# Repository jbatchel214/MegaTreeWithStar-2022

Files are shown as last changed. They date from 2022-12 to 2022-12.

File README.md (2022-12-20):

# Mega Tree 2022

In 2022 I built a Mega Tree with a 3D printed, 26 point Moravian star. The tree consisted of 27 strands of ws2811 led pixels. The 3D printed star totaled 113 pixels. The entire tree is controlled by an ESP32.

## Folder Structure

**MegaTreeAndStar**  This is the PlatformIO project of the tree code

**MoravianStar-FreeCAD**  This is the FreeCAD files for the 3D Printed Moravian Star

**MoravianStar-OBJs**  This is all the OBJs used with by the slicer

## Tree Assembly
The 27 strands for the tree are run off 9 pins on the ESP32, meaning 3 strands are run in series off of the pin. The strands are wired such that the strands are wired from bottom to top, then top to bottom, then bottom to top. On that first strand per pin, power is injected. There is additional power injection in between strands 2 and 3:

    Tree Top

        |--->|    |     |--->|    |
        |    |    |     |    |    |
        |    |    |     |    |    |
        |    |    |     |    |    |
        |    |    |     |    |    |
        |    |--->|     |    |--->|   Repeat for remaining strands
        ^    ^          ^    ^ 
       Pin1  |        Pin2   |
            Pwr             Pwr

    Tree Bottom

There are 65 lights per strand, for a total of 195 lights running off each pin. 12mm pixel mounting strips were used to space out the lights and keep them oriented.  I used every 3rd hole for 3" spacing.

There are several options for the center tree support.  I used the "ASAP Pole" and a "Portable Hole" for the base of the tree.  I have 3 guy lines to support it in the case of winds with rebar anchors as supports.

## Star Assembly:

The 3D printed star uses:
 - 17 of the Square Point files
 - 8 of the Triangle Point files
 - 1 of the pipe support
 - 4 of the cross supports
 - 12 of the center light supports
 - 1 of the Pipe Cover Point
 - 88 of the clips (I found an issue with the triangle points where they interfere on adjacent sides - I replaced some of the plastic clips with metal automotive trip clips)
 - you'll also need a 1" steel pipe.  I used an 18" pipe with a matching floor flange on the bottom.
 - you may not need it, but I included grooves for hose clamps (I used 1 to 3" clamps)

1) 4 pixels were installed into each of the square points (including the pipe cover point)
2) 3 pixels were installed into each of the triangle points
3) a single pixel was installed into each of the center lights supports, each of the cross supports, and the main pipe support
4) The center light supports are installed into the square hole in the center of the square points (they just snap in place) - output wires from the center light are fed into the input of the other 4 lights on the square point
5) The four cross supports are also isntalled into the square hole in the center of the square points
Note:  There should be one square point that does not have anything in it's center square hole... the main pipe support will go here, but I found that it was easier to assemble by putting this in last
6) Start with the square point that is missing the center light and attach 2 of the clips to one of its lower edges
7) Take another square point and slide it into the clips, then push the clips in place until they "snap" in.  Connect the wires from the previous point to the next one
8) A triangle point then installs next to that new square, then another square point, etc. all around
9) The next layer is all square points, however 4 of them are the ones with the cross support lights installed (be aware of the orientation of the square hole in the top-most point and the cross supports and how those all align with the main pipe support)
10) The next layer is square points and triangles again
11) Install the main pipe support (You're pushing this into the ball so that the light on the top of it slides into the square hole in the top-most point, and the cross supports settle into the supports in the main pipe support.  I found hanging a string from each of the cross supports helped, then when I went to "snap them in" I pulled down on the string and they popped in place nicely)
12) Slide the pipe cover point down onto the point (you could do this later if you're not using a floor flange)... also, if you have already installed the floor flange then slide the hose clamps into the right place now
13) Slide the main pipe support over the steel pipe, and optionally install the hose clamp over the groove on the main pipe support and tighten
14) Slide the pipe cover point into place, install the hose clamp and tighten (note there's a groove in one corner of the pipe cover point - this is to allow a space for the wires to come out)

I'm not defining connectors or how to make connections.  I leave this to the user based on their project demands.  I also do not describe how I managed power or wired my control box.  I don't think the low voltage of the LED strips pose a risk, but I'm no expert.  And the 120V (or 240V depending on country) can be dangerous, so do your research. 

Known issues with the 3D printed star:
1) Some of the clips interfere especially on adjacent sides of the triangular points, I found these worked well:  https://www.amazon.com/dp/B09PRF2Y5S?psc=1&ref=ppx_yo2ov_dt_b_product_details although you have to spread them a bit or they bite into the plastic
2) The assembly is difficult - a better approach would be a central frame that holds the lights and wiring and points are then "snapped in" from the outside-in
3) The mapping of the LEDs in the 3D star still needs some work

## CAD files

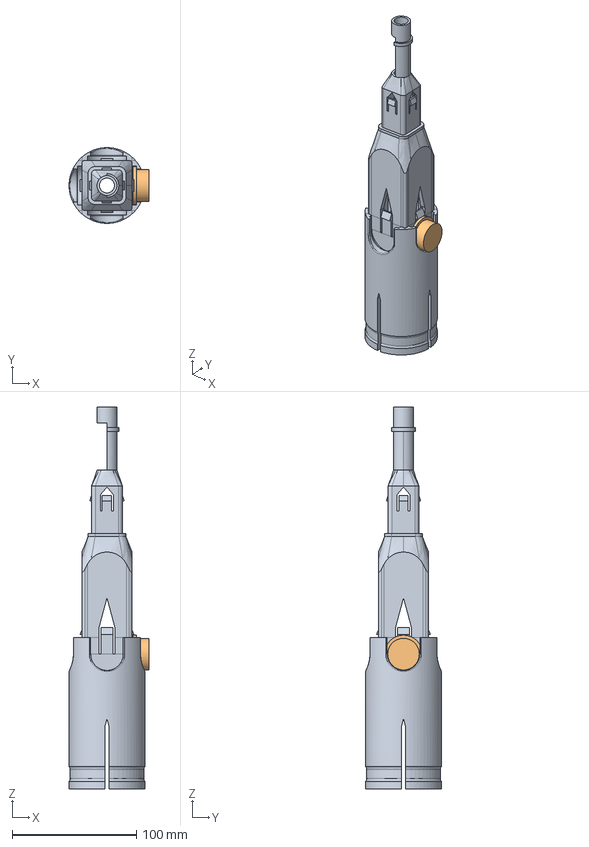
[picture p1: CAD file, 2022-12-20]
MoravianStar-FreeCAD/PipeFitting_R3.FCStd
64.2 x 61.0 x 307.3 mm
PipeSupport

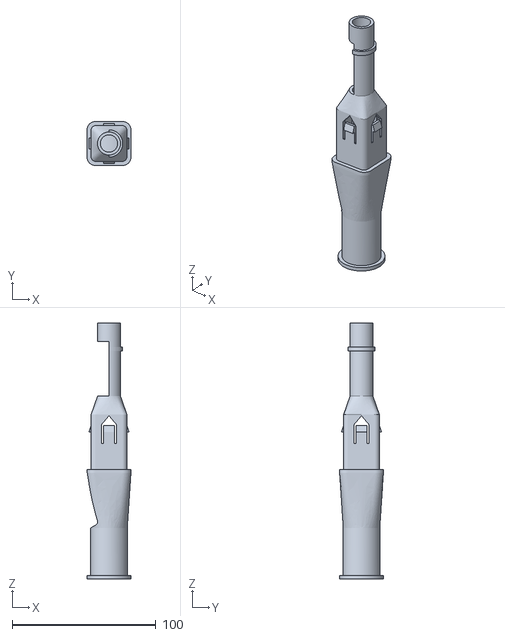
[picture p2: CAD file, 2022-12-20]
MoravianStar-OBJs/CrossSupport_R3-PipeSupport.obj
30.5 x 30.5 x 177.8

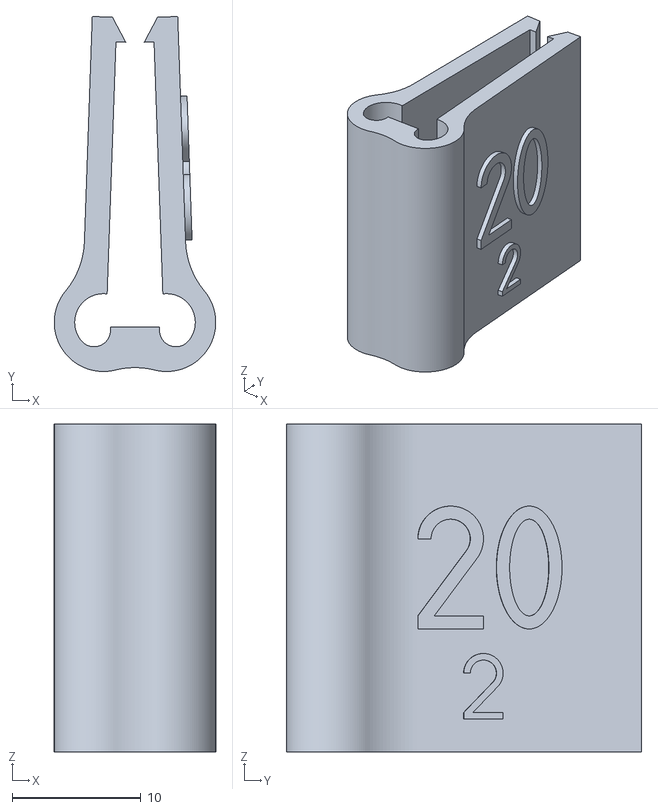
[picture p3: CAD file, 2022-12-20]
MoravianStar-OBJs/Clips_plus020_rev2-Body.obj
12.5 x 27.5 x 25.4

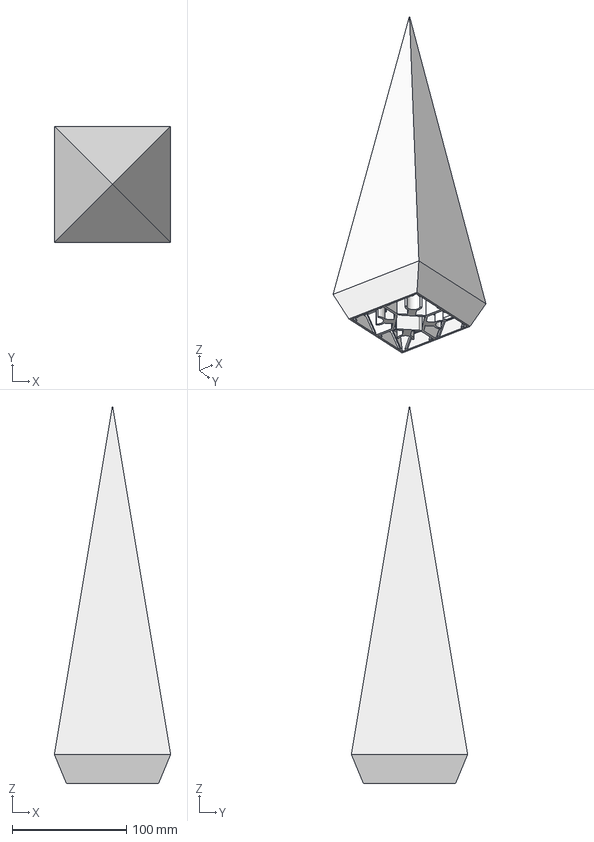
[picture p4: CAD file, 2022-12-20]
MoravianStar-FreeCAD/SquarePoint_4inBase_12inTall_NoBaseReq_rev2.FCStd
101.6 x 101.6 x 330.2 mm

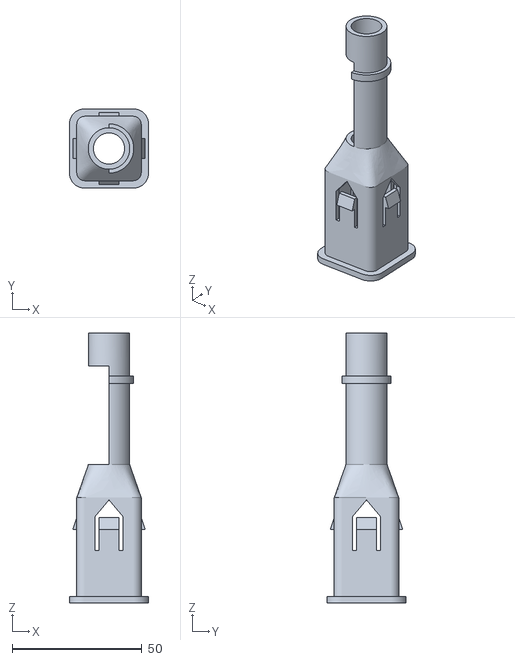
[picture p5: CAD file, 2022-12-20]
MoravianStar-OBJs/CenterLightSupport-Body.obj
30.5 x 30.5 x 104.1

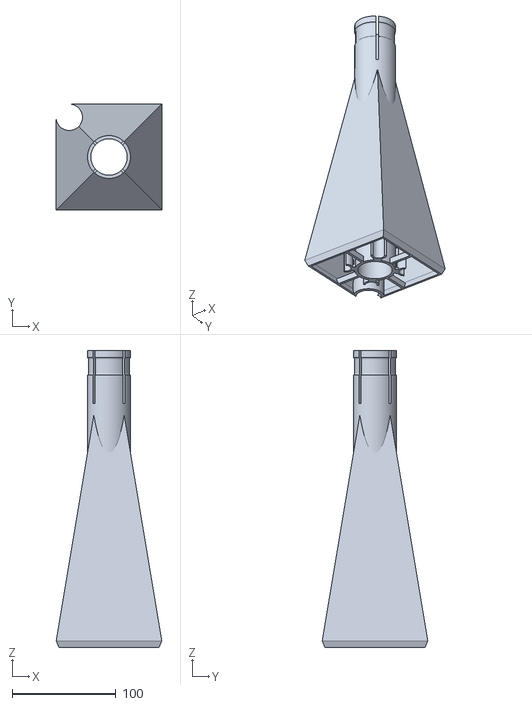
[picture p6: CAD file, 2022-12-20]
MoravianStar-OBJs/Pipe_Cover_Point_rev2-Body.obj
101.6 x 101.6 x 285.7

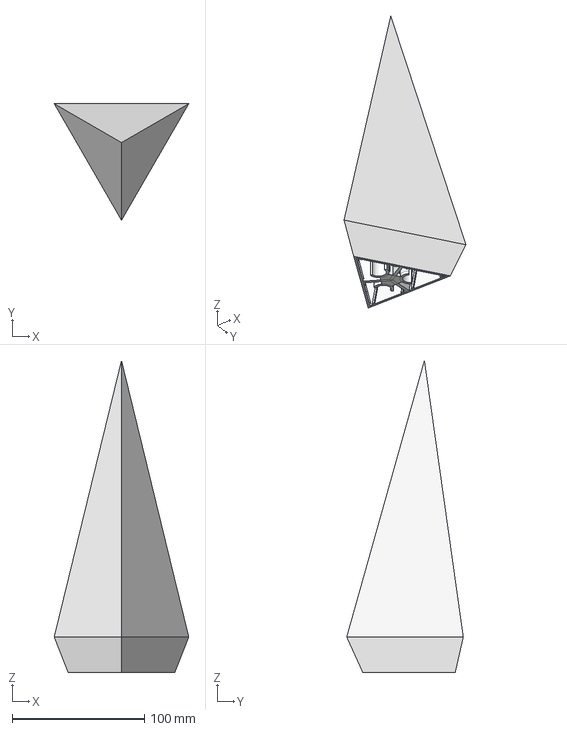
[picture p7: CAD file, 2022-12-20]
MoravianStar-FreeCAD/TrianglePoint_4inBase_7degTaper_NoBaseReq_rev3.FCStd
101.6 x 88.0 x 235.5 mm

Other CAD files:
MoravianStar-FreeCAD/CrossSupport_R3.FCStd
MoravianStar-FreeCAD/Clips_plus020_rev2.FCStd
MoravianStar-OBJs/SquarePoint_4inBase_12inTall_NoBaseReq_rev2-Body.obj
MoravianStar-FreeCAD/CenterLightSupport.FCStd
MoravianStar-OBJs/TrianglePoint_4inBase_7degTaper_NoBaseReq_rev3-Body.obj

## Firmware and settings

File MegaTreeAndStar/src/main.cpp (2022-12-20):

#include <Arduino.h>
#include <FastLED.h>
#include "driver/adc.h"

void clamp(int &val, int min, int max);
CRGB blendRGB(CRGB & startRGB, CRGB & endRGB, float pcnt);
bool angleInRange(float val, float minT, float maxT);
void SetupStar();
void SetupXMASTree();
void SetStarHSV(CHSV hsvLoc);
void SetTreeHSV(CHSV hsvLoc);
void TreeColorDrops(CHSV hsvBase);
//void TreeSpiralSolid(CHSV hsvBase, float theta, float dTheta, float omega, CHSV spiral);
void TreeSpiralRainbow(CHSV hsvBase, float theta, float dTheta, float omega, uint8_t spiralType, CHSV spiralStart, float spiraldTheta);
void TreeMeteors(CHSV hsvBase);
void CyclePixelColors(uint8_t deltaVal);
void CyclePointColors(uint8_t shiftVal, uint8_t deltaVal);

#define BRIGHTNESS 255
#define starValue 255
#define treeValue 155

#define STARPIN 27
#define NUMSTARLEDS 113

#define STRANDPIN00 16
#define STRANDPIN01 17
#define STRANDPIN02 18
#define STRANDPIN03 19
#define STRANDPIN04 21
#define STRANDPIN05 22
#define STRANDPIN06 23
#define STRANDPIN07 25
#define STRANDPIN08 26
#define NUMSTRANDLEDS 65
#define NUMSTRANDS 27
#define NUMSTRANDSPERPIN 3
#define NUMSTRANDPINS NUMSTRANDS/NUMSTRANDSPERPIN
#define NUMSTRANDLEDSPERPIN NUMSTRANDSPERPIN * NUMSTRANDLEDS
#define NUMTREELEDS NUMSTRANDS*NUMSTRANDLEDS

/* LED Arrays */
CRGB starLEDs[NUMSTARLEDS];
CRGB strandLEDsWired[NUMSTRANDPINS][NUMSTRANDLEDSPERPIN]; // these are as-wired, so bottom to top, top to bottom, bottom to top

/* universal constants */
float pi = 2.0*acosf(0.0);
float d2r = pi/180;
float r2d = 180/pi;


/* define geometries */

// define tree geometry
float firstAngle_rad = -130.0*d2r;
float lastAngle_rad = 130.0*d2r;
float baseDiam_in = 120.0;
float topDiam_in = 12.0;
float spaceInit_in = 3.0;
float spaceFinal_in = 3.0;
float gapPerLights_in = 3.0;
float vertexHeight_in = 0.0;
float treeX[NUMSTRANDPINS][NUMSTRANDLEDSPERPIN]; // x is towards road
float treeY[NUMSTRANDPINS][NUMSTRANDLEDSPERPIN]; // y is towards driveway
float treeZ[NUMSTRANDPINS][NUMSTRANDLEDSPERPIN]; // z is vertical up
float treeR[NUMSTRANDPINS][NUMSTRANDLEDSPERPIN]; // radially from center
float treeL[NUMSTRANDPINS][NUMSTRANDLEDSPERPIN]; // Length along strand
float treeT[NUMSTRANDPINS][NUMSTRANDLEDSPERPIN]; // Theta, measured from +X towards +Y (about +Z)
int treeLEDMap[NUMSTRANDS][NUMSTRANDLEDS][2]; // index map of each strand, sorted bottom to top per strand - useful for following something down a strand



// define star geoemtry
int starPoint[NUMSTARLEDS] = {0, 0, 0, 0, 0, 8, 8, 8, 8, 8, 7, 7, 7, 6, 6, 6, 6, 6, 5, 5, 5, 4, 4, 4, 4, 4, 3, 3, 3, 2, 2, 2, 2, 2, 1, 1, 1, 16, 16, 16, 16, 16, 15, 15, 15, 15, 15, 14, 14, 14, 14, 14, 13, 13, 13, 13, 13, 12, 12, 12, 12, 12, 11, 11, 11, 11, 11, 10, 10, 10, 10, 10, 9, 9, 9, 9, 9, 17, 17, 17, 24, 24, 24, 24, 24, 23, 23, 23, 22, 22, 22, 22, 22, 21, 21, 21, 20, 20, 20, 20, 20, 19, 19, 19, 18, 18, 18, 18, 18, 25, 25, 25, 25};
int starPointType[NUMSTARLEDS] = {0, 0, 0, 0, 0, 0, 0, 0, 0, 0, 1, 1, 1, 0, 0, 0, 0, 0, 1, 1, 1, 0, 0, 0, 0, 0, 1, 1, 1, 0, 0, 0, 0, 0, 1, 1, 1, 0, 0, 0, 0, 0, 0, 0, 0, 0, 0, 0, 0, 0, 0, 0, 0, 0, 0, 0, 0, 0, 0, 0, 0, 0, 0, 0, 0, 0, 0, 0, 0, 0, 0, 0, 0, 0, 0, 0, 0, 1, 1, 1, 0, 0, 0, 0, 0, 1, 1, 1, 0, 0, 0, 0, 0, 1, 1, 1, 0, 0, 0, 0, 0, 1, 1, 1, 0, 0, 0, 0, 0, 0, 0, 0, 0};
int starLocation[NUMSTARLEDS] = {0, 4, 1, 2, 3, 0, 2, 1, 4, 3, 10, 2, 1, 0, 1, 2, 3, 4, 0, 2, 1, 0, 4, 3, 2, 1, 2, 1, 0, 0, 4, 3, 2, 1, 2, 1, 0, 0, 4, 3, 2, 1, 0, 2, 1, 4, 3, 0, 1, 2, 3, 4, 0, 3, 2, 1, 4, 0, 1, 4, 3, 2, 0, 3, 2, 1, 4, 0, 4, 3, 2, 1, 0, 2, 3, 4, 1, 2, 1, 0, 0, 2, 3, 4, 1, 0, 2, 1, 0, 4, 3, 2, 1, 0, 2, 1, 0, 2, 3, 4, 1, 2, 0, 1, 0, 4, 3, 2, 1, 4, 3, 2, 1};
float starRadius[NUMSTARLEDS] = {8.000, 5.000, 5.000, 5.000, 5.000, 8.000, 5.000, 5.000, 5.000, 5.000, 5.000, 5.000, 5.000, 8.000, 5.000, 5.000, 5.000, 5.000, 5.000, 5.000, 5.000, 8.000, 5.000, 5.000, 5.000, 5.000, 5.000, 5.000, 5.000, 8.000, 5.000, 5.000, 5.000, 5.000, 5.000, 5.000, 5.000, 8.000, 5.000, 5.000, 5.000, 5.000, 8.000, 5.000, 5.000, 5.000, 5.000, 8.000, 5.000, 5.000, 5.000, 5.000, 8.000, 5.000, 5.000, 5.000, 5.000, 8.000, 5.000, 5.000, 5.000, 5.000, 8.000, 5.000, 5.000, 5.000, 5.000, 8.000, 5.000, 5.000, 5.000, 5.000, 8.000, 5.000, 5.000, 5.000, 5.000, 5.000, 5.000, 5.000, 8.000, 5.000, 5.000, 5.000, 5.000, 5.000, 5.000, 5.000, 8.000, 5.000, 5.000, 5.000, 5.000, 5.000, 5.000, 5.000, 8.000, 5.000, 5.000, 5.000, 5.000, 5.000, 5.000, 5.000, 8.000, 5.000, 5.000, 5.000, 5.000, 5.000, 5.000, 5.000, 5.000};
float starAzimuth[NUMSTARLEDS] = {0.000, 270.000, 0.000, 90.000, 180.000, 315.000, 326.250, 303.750, 300.000, 330.000, 270.000, 281.250, 258.750, 225.000, 213.750, 236.250, 240.000, 210.000, 180.000, 191.250, 168.750, 135.000, 120.000, 150.000, 146.250, 123.750, 101.250, 78.750, 90.000, 45.000, 30.000, 60.000, 56.250, 33.750, 11.250, 348.750, 0.000, 315.000, 303.750, 326.250, 326.250, 303.750, 270.000, 281.250, 258.750, 258.750, 281.250, 225.000, 213.750, 236.250, 236.250, 213.750, 180.000, 191.250, 191.250, 168.750, 168.750, 135.000, 123.750, 123.750, 146.250, 146.250, 90.000, 101.250, 101.250, 78.750, 78.750, 45.000, 33.750, 56.250, 56.250, 33.750, 0.000, 11.250, 11.250, 348.750, 348.750, 11.250, 0.000, 348.750, 315.000, 330.000, 326.250, 303.750, 300.000, 258.750, 281.250, 270.000, 225.000, 213.750, 236.250, 240.000, 210.000, 168.750, 191.250, 180.000, 135.000, 150.000, 146.250, 123.750, 120.000, 101.250, 78.750, 90.000, 45.000, 33.750, 56.250, 60.000, 30.000, 180.000, 270.000, 0.000, 90.000};
float starElevation[NUMSTARLEDS] = {0.000, 15.000, 15.000, 15.000, 15.000, 45.000, 60.000, 60.000, 30.000, 30.000, 30.000, 60.000, 60.000, 45.000, 60.000, 60.000, 30.000, 30.000, 30.000, 60.000, 60.000, 45.000, 30.000, 30.000, 60.000, 60.000, 60.000, 60.000, 30.000, 45.000, 30.000, 30.000, 60.000, 60.000, 60.000, 60.000, 30.000, 90.000, 75.000, 75.000, 105.000, 105.000, 90.000, 105.000, 105.000, 75.000, 75.000, 90.000, 105.000, 105.000, 75.000, 75.000, 90.000, 75.000, 105.000, 105.000, 75.000, 90.000, 105.000, 75.000, 75.000, 105.000, 90.000, 75.000, 105.000, 105.000, 75.000, 90.000, 75.000, 75.000, 105.000, 105.000, 90.000, 105.000, 75.000, 75.000, 105.000, 120.000, 150.000, 120.000, 135.000, 150.000, 120.000, 120.000, 150.000, 120.000, 120.000, 150.000, 135.000, 120.000, 120.000, 150.000, 150.000, 120.000, 120.000, 150.000, 135.000, 150.000, 120.000, 120.000, 150.000, 120.000, 120.000, 150.000, 135.000, 120.000, 120.000, 150.000, 150.000, 165.000, 165.000, 165.000, 165.000};
float starX[NUMSTARLEDS] = {0.000, 0.000, 1.294, 0.000, -1.294, 4.000, 3.600, 2.406, 1.250, 2.165, 0.000, 0.845, -0.845, -4.000, -3.600, -2.406, -1.250, -2.165, -2.500, -4.247, -4.247, -4.000, -1.250, -2.165, -3.600, -2.406, -0.845, 0.845, 0.000, 4.000, 2.165, 1.250, 2.406, 3.600, 4.247, 4.247, 2.500, 5.657, 2.683, 4.016, 4.016, 2.683, 0.000, 0.942, -0.942, -0.942, 0.942, -5.657, -4.016, -2.683, -2.683, -4.016, -8.000, -4.737, -4.737, -4.737, -4.737, -5.657, -2.683, -2.683, -4.016, -4.016, 0.000, -0.942, -0.942, 0.942, 0.942, 5.657, 4.016, 2.683, 2.683, 4.016, 8.000, 4.737, 4.737, 4.737, 4.737, 4.247, 2.500, 4.247, 4.000, 2.165, 3.600, 2.406, 1.250, -0.845, 0.845, 0.000, -4.000, -3.600, -2.406, -1.250, -2.165, -4.247, -4.247, -2.500, -4.000, -2.165, -3.600, -2.406, -1.250, -0.845, 0.845, 0.000, 4.000, 3.600, 2.406, 1.250, 2.165, -1.294, 0.000, 1.294, 0.000};
float starY[NUMSTARLEDS] = {0.000, -1.294, 0.000, 1.294, 0.000, -4.000, -2.406, -3.600, -2.165, -1.250, -2.500, -4.247, -4.247, -4.000, -2.406, -3.600, -2.165, -1.250, 0.000, -0.845, 0.845, 4.000, 2.165, 1.250, 2.406, 3.600, 4.247, 4.247, 2.500, 4.000, 1.250, 2.165, 3.600, 2.406, 0.845, -0.845, 0.000, -5.657, -4.016, -2.683, -2.683, -4.016, -8.000, -4.737, -4.737, -4.737, -4.737, -5.657, -2.683, -4.016, -4.016, -2.683, 0.000, -0.942, -0.942, 0.942, 0.942, 5.657, 4.016, 4.016, 2.683, 2.683, 8.000, 4.737, 4.737, 4.737, 4.737, 5.657, 2.683, 4.016, 4.016, 2.683, 0.000, 0.942, 0.942, -0.942, -0.942, 0.845, 0.000, -0.845, -4.000, -1.250, -2.406, -3.600, -2.165, -4.247, -4.247, -2.500, -4.000, -2.406, -3.600, -2.165, -1.250, 0.845, -0.845, 0.000, 4.000, 1.250, 2.406, 3.600, 2.165, 4.247, 4.247, 2.500, 4.000, 2.406, 3.600, 2.165, 1.250, 0.000, -1.294, 0.000, 1.294};
float starZ[NUMSTARLEDS] = {8.000, 4.830, 4.830, 4.830, 4.830, 5.657, 2.500, 2.500, 4.330, 4.330, 4.330, 2.500, 2.500, 5.657, 2.500, 2.500, 4.330, 4.330, 4.330, 2.500, 2.500, 5.657, 4.330, 4.330, 2.500, 2.500, 2.500, 2.500, 4.330, 5.657, 4.330, 4.330, 2.500, 2.500, 2.500, 2.500, 4.330, 0.000, 1.294, 1.294, -1.294, -1.294, 0.000, -1.294, -1.294, 1.294, 1.294, 0.000, -1.294, -1.294, 1.294, 1.294, 0.000, 1.294, -1.294, -1.294, 1.294, 0.000, -1.294, 1.294, 1.294, -1.294, 0.000, 1.294, -1.294, -1.294, 1.294, 0.000, 1.294, 1.294, -1.294, -1.294, 0.000, -1.294, 1.294, 1.294, -1.294, -2.500, -4.330, -2.500, -5.657, -4.330, -2.500, -2.500, -4.330, -2.500, -2.500, -4.330, -5.657, -2.500, -2.500, -4.330, -4.330, -2.500, -2.500, -4.330, -5.657, -4.330, -2.500, -2.500, -4.330, -2.500, -2.500, -4.330, -5.657, -2.500, -2.500, -4.330, -4.330, -4.830, -4.830, -4.830, -4.830};



int starPattern = 1;
int treePattern = 3;
bool treeTransition = false;

void setup() {
  // put your setup code here, to run once:
  adc_power_acquire(); // this was done because of an interrupt issue causing flickering

  //Serial.begin(115200);

  // setup star geometry
  //Serial.println("Starting Tree Setup");
  // setup tree geometry
  SetupXMASTree();
  //Serial.println("Finished Tree Setup");

  FastLED.addLeds<WS2811, STARPIN, RGB>(starLEDs, NUMSTARLEDS);
  //FastLED.addLeds<WS2811, STRANDPIN01, RGB>(strandLEDsIdeal[0], NUMSTRANDLEDS);
  FastLED.addLeds<WS2811, STRANDPIN00, RGB>(strandLEDsWired[0], NUMSTRANDLEDSPERPIN);
  FastLED.addLeds<WS2811, STRANDPIN01, RGB>(strandLEDsWired[1], NUMSTRANDLEDSPERPIN);
  FastLED.addLeds<WS2811, STRANDPIN02, RGB>(strandLEDsWired[2], NUMSTRANDLEDSPERPIN);
  FastLED.addLeds<WS2811, STRANDPIN03, RGB>(strandLEDsWired[3], NUMSTRANDLEDSPERPIN);
  FastLED.addLeds<WS2811, STRANDPIN04, RGB>(strandLEDsWired[4], NUMSTRANDLEDSPERPIN);
  FastLED.addLeds<WS2811, STRANDPIN05, RGB>(strandLEDsWired[5], NUMSTRANDLEDSPERPIN);
  FastLED.addLeds<WS2811, STRANDPIN06, RGB>(strandLEDsWired[6], NUMSTRANDLEDSPERPIN);
  FastLED.addLeds<WS2811, STRANDPIN07, RGB>(strandLEDsWired[7], NUMSTRANDLEDSPERPIN);
  FastLED.addLeds<WS2811, STRANDPIN08, RGB>(strandLEDsWired[8], NUMSTRANDLEDSPERPIN);
  
  // set the global brightness parameter
  FastLED.setBrightness(BRIGHTNESS);

}

void loop() {
  static unsigned long dTime = 20;
  static unsigned long frms = 0;
  const static unsigned long maxFrms = 1000;
  const static int transitionFrms = 40;
  const static int transitionRate = BRIGHTNESS/(transitionFrms-1);
  //static int transitionFrameCount = -transitionFrms;

  switch (starPattern) {
    case 0: {// solid star, vary hue vs time
      static uint8_t frameCnt = 0;
      static CHSV hsvLoc = {0, 255, starValue};
      SetStarHSV(hsvLoc);
      frameCnt++;
      if(frameCnt > 2) {
        hsvLoc.h++;
        frameCnt = 0;
      }
      break;
    }
    case 1: {// individual points cycle their own colors
      static uint8_t shiftVal = 10; // shift from time step to time step
      static uint8_t deltaVal = 70; // delta from point to point
      CyclePointColors(shiftVal, deltaVal);
      break;
    }
    case 2: { // cycle all pixels uniquely
      static uint8_t deltaVal = 70; // delta from point to point
      CyclePixelColors(deltaVal);
      break;
    }
    default: {
      starPattern = 0;
      break;
    }
  }
  //FastLED.show();
  
  switch (treePattern) {
    case 0: {// solid tree, vary hue vs time
      static CHSV hsvLoc = {0, 255, treeValue};
      SetTreeHSV(hsvLoc);
      hsvLoc.h++;
      break;
    }
    case 1: { // solid tree, but "drops" of color
      static CHSV hsvBase = rgb2hsv_approximate(CRGB::DarkGreen);
      TreeColorDrops(hsvBase);
      break;
    }
    case 2: { // tree spiral
      static CHSV hsvBase = rgb2hsv_approximate(CRGB::DarkGreen);
      static CHSV spiral = rgb2hsv_approximate(CRGB::Purple);
      static float theta_rad = 0.0*d2r;
      static float deltaTheta_rad = 180.0*d2r;
      static float omega_rps = 10.0*d2r;
      //theta_rad = fmodf(theta_rad+pi, 2*pi)-pi;
      TreeSpiralRainbow(hsvBase, theta_rad, deltaTheta_rad, omega_rps, 0, spiral, 0.0);
      theta_rad += 3.0*d2r;
      break;
    }//*/
    case 3: { // rainbow spiral
      static CHSV hsvBase = rgb2hsv_approximate(CRGB::DarkGreen);
      static CHSV spiral = {0,255,treeValue};
      static float theta_rad = 0.0*d2r;
      static float deltaTheta_rad = 180.0*d2r;
      static float omega_rps = 10.0*d2r;
      //theta_rad = fmodf(theta_rad+pi, 2*pi)-pi;
      TreeSpiralRainbow(hsvBase, theta_rad, deltaTheta_rad, omega_rps, 1, spiral, 4.0);
      theta_rad += 3.0*d2r;
      spiral.h+=10;
      break;
    }//*/
    default: {
      treePattern = 0;
      break;
    }
  }

  frms++;
  int tmpBrightness = BRIGHTNESS;
  if (frms<transitionFrms){ // initial ramp up in brightness
    tmpBrightness = transitionRate * frms;
    clamp(tmpBrightness, 0, 255);
  }
  else if (frms<transitionFrms + maxFrms) { // constant brightness
    tmpBrightness = BRIGHTNESS;
  }
  else if (frms<transitionFrms + maxFrms + transitionFrms) { // rampdown to transition
    int transitionCnt = transitionFrms - (frms - transitionFrms - maxFrms);
    tmpBrightness = transitionRate * transitionCnt;
    clamp(tmpBrightness, 0, 255);
    FastLED.setBrightness(tmpBrightness);
  } else {
    tmpBrightness = 0;
    treePattern++;
    frms = 0;
    //Serial.printf(" New Tree Pattern:  %d\n", treePattern);
  }
  //Serial.printf("Frame:  %d     Brightness:  %d\n", frms, tmpBrightness);
  FastLED.setBrightness(tmpBrightness);

  FastLED.show();
  FastLED.delay(dTime);

}


/* Utility Functions */
void clamp(int &val, int min, int max) {
  if (val < min) {
    val = min;
  }
  else if (val > max) {
    val = max;
  }
}

CRGB blendRGB(CRGB & startRGB, CRGB & endRGB, float pcnt) {
  CRGB output;
  // Linearly interpolates in R, G, B color space between 2 colors
  int tmpRed   = int(float(endRGB.r - startRGB.r)*pcnt + float(startRGB.r) + 0.5);
  int tmpGreen = int(float(endRGB.g - startRGB.g)*pcnt + float(startRGB.g) + 0.5);
  int tmpBlue  = int(float(endRGB.b - startRGB.b)*pcnt + float(startRGB.b) + 0.5);
  clamp(tmpRed, 0, 255);
  clamp(tmpGreen, 0, 255);
  clamp(tmpBlue, 0, 255);
  output.r = tmpRed;
  output.g = tmpGreen;
  output.b = tmpBlue;
  return output;
}

bool angleInRange(float val, float minT, float maxT) {
  // checks if an angle is between min and max angle (around a 360deg circle)
  val = fmodf(val + pi, 2*pi) - pi;
  minT = fmodf(minT + pi, 2*pi) - pi;
  maxT = fmodf(maxT + pi, 2*pi) - pi;
  if (maxT > minT) {
    if ((minT <= val) & (val <= maxT)) { return true; }
    else { return false; }
  }
  else {
    if ((maxT <  val) & (val <  minT)) { return false; }
    else { return true; }
  }
}

float smallestAngle(float val, float ref) {
  // finds the smallest angle between the val and the ref, non directional
  float diff = fmodf(val - ref + pi, 2*pi) - pi;
  diff = (diff < -pi) ? diff + 2*pi : diff;
  return (diff < 0) ? -diff : diff;
}

/* Setup Functions */

void SetupStar() {}

void SetupXMASTree() {
  //Serial.println("Detailed Tree Setup");
  // strands are wired in pairs of 3, going bottom to top, top to bottom, bottom to top
  float strandLength_in = float(NUMSTRANDLEDS - 1)*gapPerLights_in + spaceInit_in + spaceFinal_in;
  float verticalLength_in = sqrt(strandLength_in*strandLength_in - (0.5*(baseDiam_in - topDiam_in))*(0.5*(baseDiam_in - topDiam_in)));
  vertexHeight_in = verticalLength_in * baseDiam_in / (baseDiam_in - topDiam_in);
  float vertexLength_in = sqrt(vertexHeight_in*vertexHeight_in + baseDiam_in*baseDiam_in);
  float strandTiltAngle_rad = atan2f(baseDiam_in - topDiam_in, verticalLength_in);
  
  int iStrand = 0;
  for (int iP = 0; iP<NUMSTRANDPINS; iP++) { // pin, there's 9 pins and there's 3 strands per pin
    bool bottomUp = true;
    int iLwired = 0; // index of the light as it's wired on the pin
    for (int iS = 0; iS<NUMSTRANDSPERPIN; iS++) { // strand, there's 3 strands per pin
    float tmpAng = firstAngle_rad + ((lastAngle_rad - firstAngle_rad)/(float(NUMSTRANDS)-1.0))*float(iStrand);
      for (int iLcnt = 0; iLcnt<NUMSTRANDLEDS; iLcnt++) {
        // determines if you count up or down:
        int iL = (bottomUp) ? iLcnt : (NUMSTRANDLEDS-1) - iLcnt;

        // map the LEDs from "ideal" to wired:
        treeLEDMap[iStrand][iL][0] = iP;
        treeLEDMap[iStrand][iL][1] = iLwired;

        // create geometric map:
        treeT[iP][iLwired] = tmpAng;
        treeL[iP][iLwired] = spaceInit_in + float(iL)*gapPerLights_in;
        treeZ[iP][iLwired] = treeL[iP][iLwired]*cosf(strandTiltAngle_rad);
        treeR[iP][iLwired] = 0.5*baseDiam_in - treeL[iP][iL]*sinf(strandTiltAngle_rad);
        treeX[iP][iLwired] = treeR[iP][iLwired]*cosf(treeT[iP][iLwired]);
        treeY[iP][iLwired] = treeR[iP][iLwired]*sinf(treeT[iP][iLwired]);
        
        iLwired++;
      }
      bottomUp = !bottomUp;
      iStrand++;
    }
  }
}


/* Global Color Control */

void SetStarHSV(CHSV hsvLocal) {
  /* set the Star to a constant color */
  CRGB rgbLocal;
  hsv2rgb_rainbow(hsvLocal, rgbLocal);
  for (int i = 0; i<NUMSTARLEDS; i++) {
    starLEDs[i] = rgbLocal;
  }
}

void SetTreeHSV(CHSV hsvLocal) {
  /* set the Tree to a constant color */
  CRGB rgbLocal;
  hsv2rgb_rainbow(hsvLocal, rgbLocal);
  for (int iP = 0; iP< NUMSTRANDPINS; iP++) {
    for (int i = 0; i<NUMSTRANDLEDSPERPIN; i++) {
      strandLEDsWired[iP][i] = rgbLocal;
    }
  }
}


/* Color Patterns for the Tree */
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
